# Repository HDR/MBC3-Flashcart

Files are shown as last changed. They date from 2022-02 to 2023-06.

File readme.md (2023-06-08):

# Make sure you read the [LICENSE](https://github.com/HDR/MBC3-Flashcart/blob/master/LICENSE)

MBC3 Flashcart based on retroreboot's cartridge that uses 0603 components (while based on the RetroReboot carts, these are completely redesigned from the ground up in kicad)

If you want a 4MB cart check out my new [MBC30 flashcart repo](https://github.com/HDR/MBC30-Flashcart)

Version 1.5 and beyond makes use of [djedditt's](https://github.com/djedditt/) [cartridge connector footprint](https://github.com/djedditt/kicad-gamepaks)

**PCBWay:**

Purchase on PCBWay (https://www.pcbway.com/project/shareproject/MBC3_Flashcart___2x2MB___FRAM___RTC___Beta_Release__Untested_.html)

As a disclaimer, i get 10% kickback on shared pcbway orders, if you want the cheaper option go with either JLCPCB or OshPark

If you want to support me for free (and get 5 USD in new user credit) you can use my PCBWay [Referral link](https://www.pcbway.com/setinvite.aspx?inviteid=388393) when signing up on PCBWay

Referral (https://www.pcbway.com/setinvite.aspx?inviteid=388393)

**OSHPark:**

[Purchase on OSHPARK](https://oshpark.com/shared_projects/YCtVNv4A)

Make sure to select the "2 oz copper, 0.8mm thickness" option before checkout

**JLCPCB:**

Upload gerbers(.zip files) to [JLCPCB](http://jlcpcb.com)

Make sure you order with the following settings:

PCB Thickness: 0.8

PCB Color: Any

Surface Finish: ENIG-RoHS

Gold Fingers: Yes (45° chamfered border)

Castellated Holes: No

Check out the [Interactive BOM](https://hdr.github.io/ibom/MBC3-Flashcart) for an interactive website that lets you keep track of where everything goes.

## BOM

| Reference | Part Number | Description  | Package |
| :---: |:---:| :-----:| :-----:|
| U1 | AM29F016(2MB)/AM29F032(4MB)/MBM29F033C(4MB) | 2/4MB Flash Chip | TSOP-48/TSOP-40 |
| U2 | MBC3 | Get from real cartridge | LQFP-32 |
| U3 | FM18W08 | 256kbit FRAM | SOIC-28 |
| U4 | BA6129AF | Buy or get from real cartridge | SOIC-8 |
| U5 | [74LVC1G332GV,125](https://www.nexperia.com/products/analog-logic-ics/control-logic/gates/or-gates/74LVC1G332GV.html) | 3-input OR gate | TSOP-6 |
| C1 | [CL10B104KO8NNNC](https://lcsc.com/product-detail/Multilayer-Ceramic-Capacitors-MLCC-SMD-SMT_Samsung-Electro-Mechanics-CL10B104KO8NNNC_C66501.html)* | 100nF Capacitor | 0603 |
| C2 | [CL10B104KO8NNNC](https://lcsc.com/product-detail/Multilayer-Ceramic-Capacitors-MLCC-SMD-SMT_Samsung-Electro-Mechanics-CL10B104KO8NNNC_C66501.html)* | 100nF Capacitor | 0603 |
| C3 | [CL10B104KO8NNNC](https://lcsc.com/product-detail/Multilayer-Ceramic-Capacitors-MLCC-SMD-SMT_Samsung-Electro-Mechanics-CL10B104KO8NNNC_C66501.html)* | 100nF Capacitor | 0603 |
| C4 | [CL10C150JB8NNNC](https://lcsc.com/product-detail/Multilayer-Ceramic-Capacitors-MLCC-SMD-SMT_Samsung-Electro-Mechanics-CL10C150JB8NNNC_C1644.html)* | 15pF Capacitor | 0603 |
| C5 | [CL10C150JB8NNNC](https://lcsc.com/product-detail/Multilayer-Ceramic-Capacitors-MLCC-SMD-SMT_Samsung-Electro-Mechanics-CL10C150JB8NNNC_C1644.html)* | 15pF Capacitor | 0603 |
| C6 | [CL10B104KO8NNNC](https://lcsc.com/product-detail/Multilayer-Ceramic-Capacitors-MLCC-SMD-SMT_Samsung-Electro-Mechanics-CL10B104KO8NNNC_C66501.html)* | 100nF Capacitor | 0603 | 0603 |
| C7 | [CL10B104KO8NNNC](https://lcsc.com/product-detail/Multilayer-Ceramic-Capacitors-MLCC-SMD-SMT_Samsung-Electro-Mechanics-CL10B104KO8NNNC_C66501.html)* | 100nF Capacitor | 0603 |
| R1 | [RC0603FR-07330KL](https://lcsc.com/product-detail/Chip-Resistor-Surface-Mount_YAGEO-RC0603FR-07330KL_C114618.html)* | 330K Ω Resistor | 0603 |
| R2 | [RC0603FR-0710KL](https://lcsc.com/product-detail/Chip-Resistor-Surface-Mount_YAGEO-RC0603FR-0710KL_C98220.html)* | 10K Ω Resistor | 0603 |
| R3 | [RC0603FR-071KL](https://lcsc.com/product-detail/Chip-Resistor-Surface-Mount_YAGEO-RC0603FR-071KL_C22548.html)* | 1K Ω Resistor | 0603 |
| SW1 (Unmarked) | [K3-1296S-E1](https://lcsc.com/product-detail/Slide-Switches_Korean-Hroparts-Elec-K3-1296S-E1_C128955.html)** | SPDT Switch | N/A |
| X1 | R26-32.768-12.5-10PPM | 32.768 kHz Crystal | N/A |
| Batt CR2025 | BK-6219-TR | CR2025 Coin Cell Retainer | N/A |

*Linked Capacitors/Resistors are suggestions, use whatever matches the ratings and package.
**Switch is optional, and is only used with 4MB chips.

## Changelog:

**1.2:**
- Fixed missing traces

**1.3:**
- Fixed some trace issues with Y1
- Rerouted the pcb entirely

**1.4:**
- Fixed a short between A16 and VCC

**1.4.1:**
- Changed AM29F016 footprint to make chip alignment easier
- Cleaned up traces (visual)

**1.5:**
- Updated kicad version from 5 to 6.0
- Redrew outline to be a closer match to original
- Added markings to make cart look more original
- Added switch for 2x2mb mode (this means the cart can store 2 separate roms, saves are still shared)
- Changed footprint designators
- Added test pads
- Added date marking
- Relocated alignment holes for a better fit

## Images

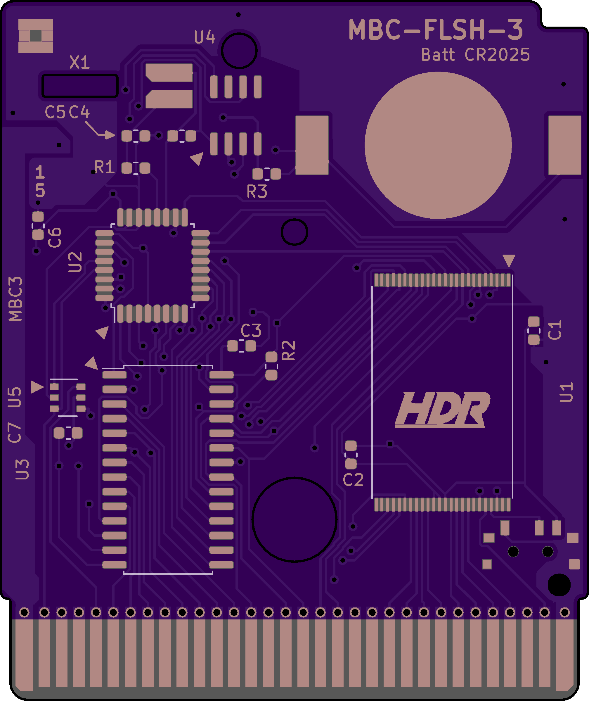
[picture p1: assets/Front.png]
Front


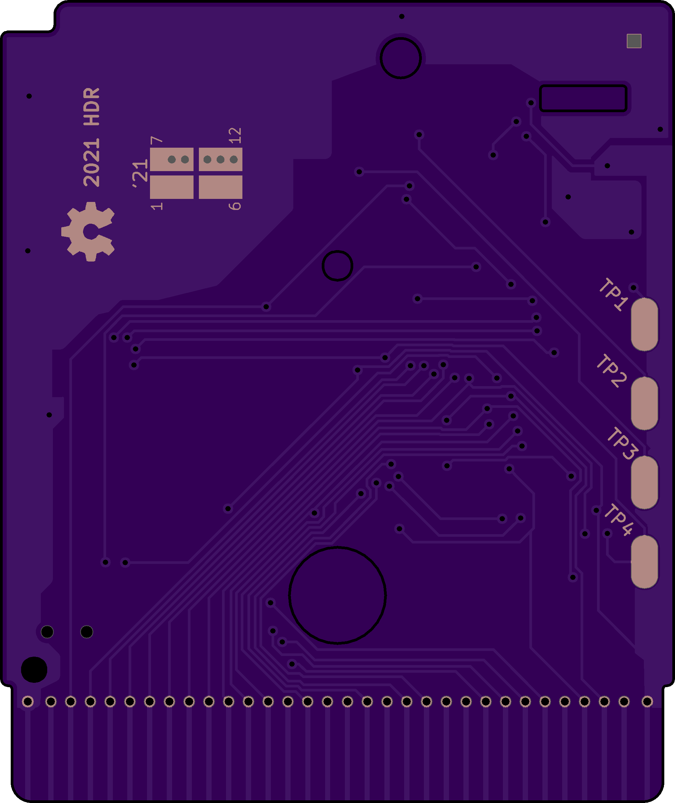
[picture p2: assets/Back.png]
Back


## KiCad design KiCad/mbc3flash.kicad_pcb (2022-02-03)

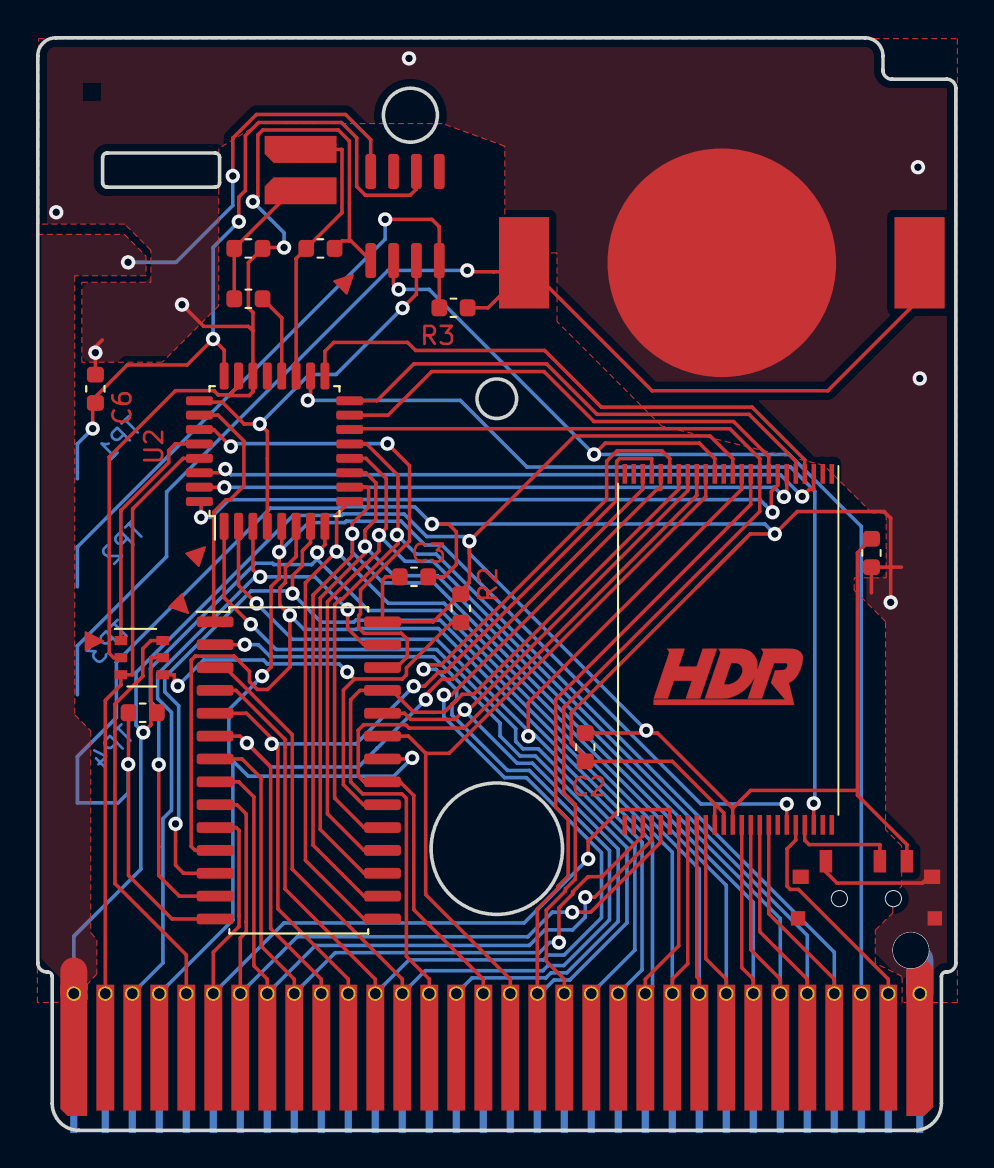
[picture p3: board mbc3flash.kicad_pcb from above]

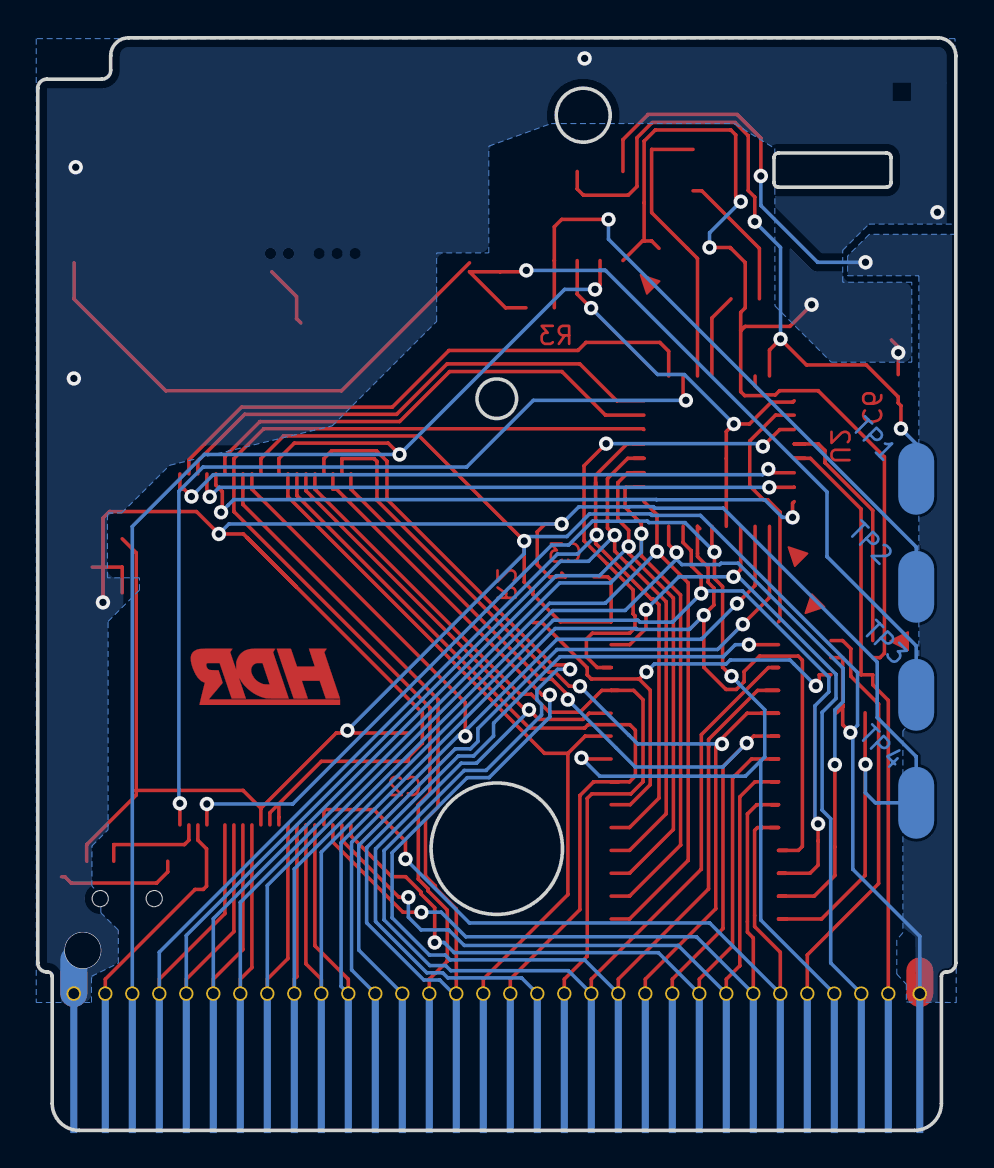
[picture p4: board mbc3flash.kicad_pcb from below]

Board: 2 copper layers, 51.0 x 60.7 mm, 25 parts (5 on the bottom side), 51 nets.

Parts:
B1: Battery_Cell; BK-6219-TR
C1, C2, C3, C6, C7: 0.1 uF; C_0603_1608Metric
C4, C5: 15 pF; C_0603_1608Metric
GNDPAD1: Nintendo_3x3_GNDPad
PAD*: GBA-ProductionIndicator
R1: 300Kohm; R_0603_1608Metric
R2: 10 Kohm; R_0603_1608Metric
R3: 1 Kohm; R_0603_1608Metric
SW1: SW_SPDT; SW_SPDT-K3-1296S-E1
TP1: RTC_VOUT; GameBoy_Testpoint
TP2: Battery_Positive_After_Resistor; GameBoy_Testpoint
TP3: Battery_Positive; GameBoy_Testpoint
TP4: Ground; GameBoy_Testpoint
U0: CartBus; GameBoy_GamePak_CGB-002_P1.50mm_Edge
U1: AM29F016; TSOP-I-48_18.4x12mm_P0.5mm
U2: MBC3
U3: FM18W08; SOIC-28W_7.5x17.9mm_P1.27mm
U4: BA6129AF; SOIC-8_3.9x4.9mm_P1.27mm
U5: 74LVC1G332GW,125; TSOP-6_1.65x3.05mm_P0.95mm
Y1: Crystal; Resonator_SMD_muRata_CDSCB-2pin_4.5x2.0mm_HandSoldering

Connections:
#CE: R2.1, U3.20, U5.4
A0: U0.6, U1.30, U3.10
A1: U0.7, U1.29, U3.9
A2: U0.8, U1.28, U3.8
A3: U0.9, U1.27, U3.7
A4: U0.10, U1.22, U3.6
A5: U0.11, U1.21, U3.5
A6: U0.12, U1.20, U3.4
A7: U0.13, U1.19, U3.3
A8: U0.14, U1.18, U3.25
A9: U0.15, U1.17, U3.24
A10: U0.16, U1.16, U3.21
A11: U0.17, U1.15, U3.23
A12: U0.18, U1.10, U3.2
A13: U0.19, U1.9, U2.14
A14: U0.20, U2.1
A15: U0.21, U1.11, U2.2
AA13: U2.27, U3.26
AA14: U2.26, U3.1
BT+: B1.1, R3.1, TP3.1
CLK: U0.2, U2.29, U5.3
CS: U0.5, U5.6
D0: U0.22, U1.31, U2.6, U3.11
D1: U0.23, U1.32, U2.7, U3.12
D2: U0.24, U1.33, U2.8, U3.13
D3: U0.25, U1.34, U2.9, U3.15
D4: U0.26, U1.38, U2.10, U3.16
D5: U0.27, U1.39, U2.11, U3.17
D6: U0.28, U1.40, U2.12, U3.18
D7: U0.29, U1.41, U2.13, U3.19
GND: B1.2, C1.1, C2.2, C3.1, C4.2, C5.1, C6.2, C7.1, SW1.1, TP4.1, U0.32, U1.35, U1.36, U2.22, U2.23, U3.14, U4.1, U5.2
unnamed: C5.2, R1.2, Y1.1
unnamed: SW1.2, U1.45
PWR: C6.1, TP1.1, U2.24, U4.6
RA14: U1.8, U2.15
RA15: U1.7, U2.32
RA16: U1.6, U2.31
RA17: U1.5, U2.16
RA18: U1.4, U2.17
RA19: U1.3, U2.30
RA20: U1.46, U2.18
RESET: U0.30, U1.14, U4.2
VCC: C1.2, C2.1, C3.2, C7.2, R2.2, SW1.3, U0.1, U1.12, U1.37, U3.28, U4.8, U5.5
Vbatt: R3.2, TP2.1, U4.4
WE_AUD: U0.31, U1.44
XIN: C4.1, U2.19, Y1.2
XOUT: R1.1, U2.20
\RAMCS: U2.28, U5.1
\RD: U0.4, U1.43, U2.5, U3.22
\RST: U2.4, U2.25, U4.3
\WR: U0.3, U2.3, U3.27

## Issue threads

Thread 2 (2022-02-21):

Version 1.5 unable to preview on JLCPCB & PCBWay

EthanChinCN, 2022-02-21:
1. Uploaded to JLCPCB or PCBWay. The preview section won't render any images
2. JCLPCB won't automatically detect dimensions, require manually input
3. JCLPCB online Gerber viewer won't render, prompt error "Unable to identify the layers due to the non-standard filename"
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

HDR, 2022-07-24:
Whoops forgot to close this, fixed with d55d2eb1419be985161d65bb1fd4a22e397ddbc2

scr-trees, 2022-10-02:
The preview is rendered on JLCPCB, but the same errors are given: "unable to identify layers", "cannot identify board outline", and several "non-gerber274x/excellon formats". Is it still ok to order?

HDR, 2022-10-02:
This is a JLC gerber rendering issue, previews on pcb manufacturing sites are often broken or just wrong.

scr-trees, 2022-10-02:
So it's fine without B_Paste.gbr?

HDR, 2022-10-03:
yes, it's just a rendering issue

Closed 2022-07-24.

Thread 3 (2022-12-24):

KiCad Schematic error

KoopsF, 2022-12-24:
Hi,

I tried opening the KiCad Schematic but I get this error:

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

Also, is there a way to see all the connections of pins, tracks, and vias just by clicking on them?

Cheers,
Frank

KoopsF, 2022-12-24:
Update on my second question:
I figured out that in the KiCad PCB Editor the **`** symbol highlights all the tracks of a connection on the PCB

The KiCad Schematic error is still there

HDR, 2022-12-25:
What version of KiCad are you using?

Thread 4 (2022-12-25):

RESET Pin 14 on ROM to RESET or (not)RESET

KoopsF, 2022-12-25:
I noticed in the PCB file that the RESET/(not)RESET pin from the ROM is connected to the RESET pin from BA6129AF.
I've seen another project making a flashcard connecting the RESET pin from the ROM to the (not)RESET pin.
The other project:
https://github.com/JRodrigoTech/FLASH-ROM-Adapter-for-GameBoy
https://www.jrodrigo.net/wiki/how-to-diy-a-gameboy-flash-cartridge-with-a-rom-adapter-board/

I'm confused about where to connect the RESET pin.
Does anybody know?

HDR, 2022-12-25:
Please don't use github issues to ask generic support questions

KoopsF, 2022-12-25:
don't be a bitch

Closed 2022-12-25.

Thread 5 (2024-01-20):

Interactive BOM Link does not work

thliedtk, 2024-01-20:
The link to the interactive BOM provided (_https://hdr.github.io/ibom/MBC3-Flashcart_) in the readme.md does not work.

samzorio, 2024-06-12:
> The link to the interactive BOM provided (_https://hdr.github.io/ibom/MBC3-Flashcart_) in the readme.md does not work.

seems like it's just a typo in the url https://martinrefseth.com/ibom/MBC3-Flashcart.html

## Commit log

2019-07-03 Redesigned carts from the ground up
    The original commits to this repo used modified versions of the
    original, as of this commit the carts are designed in Kicad from the
    ground up.
2019-07-14 1.3
    - Fixed some issues with the traces around Y1
    - Rerouted PCB
2020-05-22 Add kicad files
    Finally got around to cleaning up the project folder enough for it to be in a releaseable state.
    [mbc3flash.kicad_pcb, mbc3flash.sch]
2022-02-03 Release 1.5
    - Updated kicad version from 5 to 6.0
    - Redrew outline to be a closer match to original
    - Added markings to make cart look more original
    - Added switch for 2x2mb mode (this means the cart can store 2 separate roms, saves are still shared)
    - Changed footprint designators
    - Added test pads
    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
    [mbc3flash.kicad_pcb, mbc3flash.sch]
2022-05-27 Update Gerbers for JLCPCB
    JLC expects some specific settings to correctly render gerber files
